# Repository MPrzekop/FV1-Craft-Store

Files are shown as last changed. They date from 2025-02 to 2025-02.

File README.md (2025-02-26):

# Craft Store
#### FV-1 based multi-effect development platform that (almost) fits inside 1590b enclosure
Craft Store is a pedalboard friendly implementation of FV-1 with onboard USB programmer.
 <p align="center">
thumbnail
 </p>
 
---

How it's different
---
On top of the default signal path:
- there's physical feedback loop going from right channel output to the left channel input 
- FV-1's left channel input can be blended into the pedal's output 

Controls:
---
- 0-2 FV-1 potentiometer inputs
- Volume
- mix - full dry to full wet
- clock - 4049 based variable sampling clock 42kHz down to super glitchy 2kHz
- feed - adds FV-1's left channel output to the output signal
- toggle - switches between built-in FV-1 programs and EEPROM
- 8 position program selector

Contents:
---
- [KiCad 8.0 project ](https://github.com/MPrzekop/FV1-Craft-Store/tree/main/Hardware/KiCad)
  - 2 effect boards and optional footswitch doughterboard
<p align="center">
pcb 3d render
schematic layout
pcb layout
 </p>
 
 - [3D printing files ](https://github.com/MPrzekop/FV1-Craft-Store/tree/main/Hardware/3DPrinting)
    - Case and lid, similar to 1590b just 2mm taller 
    - Knobs for 9mm potentiometers V6 is different from V5 that it has an inset to accommodate for 8 position switch thread collar. V5 variants to use depending on filament and printer.
 - [Spincad made example programs ](https://github.com/MPrzekop/FV1-Craft-Store/tree/main/Software)

Build Guide:
---
[BOM](https://github.com/MPrzekop/FV1-Craft-Store/blob/main/Hardware/KiCad/fv1.csv).

Most of the components are SMD so it may require some experience. I've tried to preserve both component ids and values on the PCB itself for ease of build and debugging.

Couple of tips:
- with normal 2.54 sockets and pins the boards may pivot on DC jack, I've soldered sockets when the board was lying on a flat surface to get the most clearance from the pins.
- Clock potentiometer is marked as 100K, this may be excessive as below 20kHz there's an audible hiss. I've tested with 20K and it was more controllable, but still glitchy (theoretically going down to 8kHz). If what you need is longer delays without much audio degradation I'd recommend putting 5K potentiometer there.
- The board stack is slightly too tall for a normal 1590b housing, to make the housing compatible you'll need to file down the lip on the lid, or add around 2mm spacing between the housing and the lid. 

Programming Guide:
---

On the board there's a **[ch341a](https://www.wch-ic.com/products/CH341.html)** programmer and **[24lc32](https://ww1.microchip.com/downloads/en/DeviceDoc/21072G.pdf)** EEPROM so any approaches for programming those are valid.
- you'll need drivers from the [ch341a vendor's page](https://www.wch-ic.com/products/CH341.html)
- follow [this tutorial](https://wiki.pedalpcb.com/wiki/Using_the_FV1Dev_on_Microsoft_Windows) for how to program the EEPROM

Creating programs:
---

[Best place to start](https://electric-canary.com/fv1start.html)

- The easiest way, by a mile, is to use [SpinCAD designer](https://github.com/HolyCityAudio/SpinCAD-Designer) 

<p align="center">
spincad
</p>

- [SpinASM](https://spinsemi.com/products.html), FV-1 flavoured assembly 

<p align="center">
pcb 3d render
</p>

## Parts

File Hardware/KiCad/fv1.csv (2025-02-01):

Reference | Value | Datasheet | Footprint | Qty | DNP
3V3 | TestPoint | ~ | Connector_PinHeader_1.00mm:PinHeader_1x01_P1.00mm_Vertical | 1
C1,C2 | 47u | ~ | Capacitor_SMD:CP_Elec_5x5.4 | 2
C3,C4 | 20p | ~ | Capacitor_SMD:C_0603_1608Metric_Pad1.08x0.95mm_HandSolder | 2
C5,C6,C8,C9,C11,C22,C29,C31 | 100n | ~ | Capacitor_SMD:C_0603_1608Metric_Pad1.08x0.95mm_HandSolder | 8
C7 | 100u | ~ | Capacitor_SMD:CP_Elec_6.3x5.4 | 1
C10 | 330n | ~ | Capacitor_SMD:C_0603_1608Metric_Pad1.08x0.95mm_HandSolder | 1
C12,C14,C15,C16,C17,C18,C21,C24 | 1u | ~ | Capacitor_SMD:C_0603_1608Metric_Pad1.08x0.95mm_HandSolder | 8
C13,C23,C25 | 2n2 | ~ | Capacitor_SMD:C_0603_1608Metric_Pad1.08x0.95mm_HandSolder | 3
C19 | 220p | ~ | Capacitor_SMD:C_0603_1608Metric_Pad1.08x0.95mm_HandSolder | 1
C20,C28 | 470p | ~ | Capacitor_SMD:C_0603_1608Metric_Pad1.08x0.95mm_HandSolder | 2
C30 | 4.7u | ~ | Capacitor_SMD:C_0603_1608Metric_Pad1.08x0.95mm_HandSolder | 1
D1,D12 | 1N5817 | http://www.vishay.com/docs/88525/1n5817.pdf | Diode_THT:D_DO-41_SOD81_P10.16mm_Horizontal | 2
D2 | LED | ~ | LED_THT:LED_D5.0mm | 1
D3,D4,D5,D6,D7,D8,D9,D10,D11 | 1N914 | https://datasheet.octopart.com/1N914ATR-ON-Semiconductor-datasheet-42765246.pdf | Diode_SMD:D_SOD-323_HandSoldering | 9
J1 | USB_B_Micro | ~ | FV1Footrpints:USB_Micro-AB_Molex_47590-0001 | 1
J3,J9,J10 | Conn_01x02_Socket | ~ | Connector_PinSocket_2.54mm:PinSocket_1x02_P2.54mm_Vertical | 3
J4,J5,J6,J7 | Conn_01x13 | ~ | -- mixed values -- | 4
J8 | Barrel_Jack_MountingPin | ~ | Connector_BarrelJack:BarrelJack_Horizontal | 1
R1,R2,R5,R6,RV6 | 10K | ~ | -- mixed values -- | 5
R3 | 4K7 | ~ | PCM_4ms_Resistor:R_0603 | 1
R4 | 2k2 | ~ | PCM_4ms_Resistor:R_0603 | 1
R7,R8,R9,R24,RV1,RV2,RV3,RV4 | 100K | ~ | -- mixed values -- | 8
R10,R13,R16,R26 | 1K | ~ | PCM_4ms_Resistor:R_0603 | 4
R11,R12 | 1M | ~ | PCM_4ms_Resistor:R_0603 | 2
R14 | 20K | ~ | PCM_4ms_Resistor:R_0603 | 1
R15,R23 | 100 | ~ | PCM_4ms_Resistor:R_0603 | 2
R17,R18,R19,R20,R21,R22,R29,R30,R31 | 15K | ~ | PCM_4ms_Resistor:R_0603 | 9
RV5 | B10K | ~ | PCM_4ms_Potentiometer:Pot_9mm_Knurl_NoDet | 1
SW1,SW3,SW4,SW5 | SW_SPDT | ~ | -- mixed values -- | 4
SW2 | SW_Rotary_1x8_MP | ~ | FV1Footrpints:SR16 | 1
U1 | SPN1001 | http://www.spinsemi.com/Products/datasheets/spn1001/FV-1.pdf | Package_SO:SOIC-28W_7.5x17.9mm_P1.27mm | 1
U2 | L78L33_TO92 | http://www.st.com/content/ccc/resource/technical/document/datasheet/15/55/e5/aa/23/5b/43/fd/CD00000446.pdf/files/CD00000446.pdf/jcr:content/translations/en.CD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 | Package_TO_SOT_THT:TO-92_Inline | 1
U3 | 24LC32 | http://ww1.microchip.com/downloads/en/DeviceDoc/21072G.pdf | Package_DIP:DIP-8_W7.62mm_Socket | 1
U4 | CH341A |  | Package_SO:SOIC-28W_7.5x18.7mm_P1.27mm | 1
U6 | TL074 | http://www.ti.com/lit/ds/symlink/tl071.pdf | Package_DIP:DIP-14_W7.62mm_Socket | 1
U8 | ATtiny85-20P | http://ww1.microchip.com/downloads/en/DeviceDoc/atmel-2586-avr-8-bit-microcontroller-attiny25-attiny45-attiny85_datasheet.pdf | Package_DIP:DIP-8_W7.62mm | 1
Y1 | 12Mhz | ~ | Crystal:Crystal_HC49-4H_Vertical | 1

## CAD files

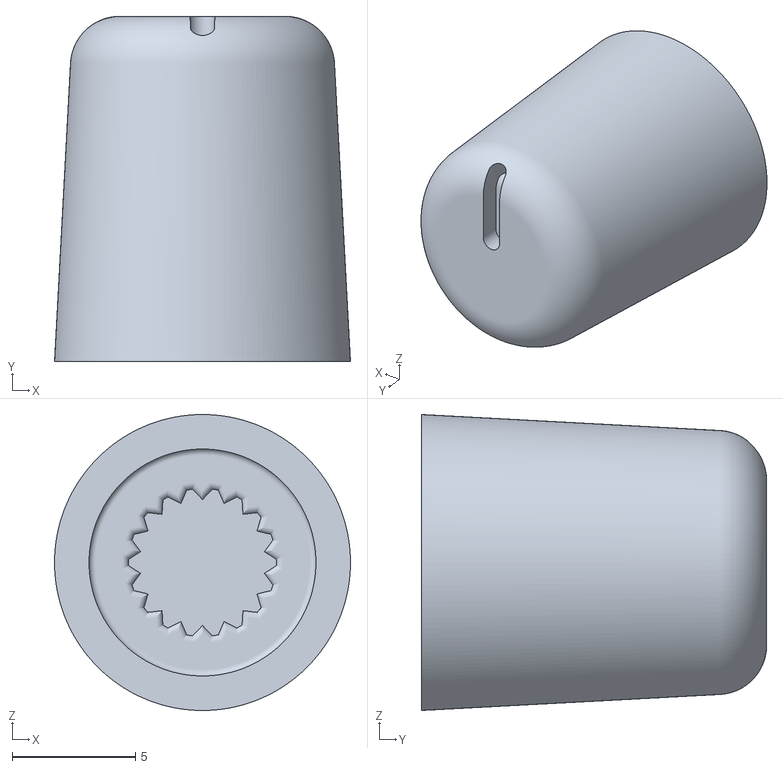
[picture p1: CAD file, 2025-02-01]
Hardware/3DPrinting/Knob v5 0 tolerance.stl
12.0 x 14.0 x 12.0

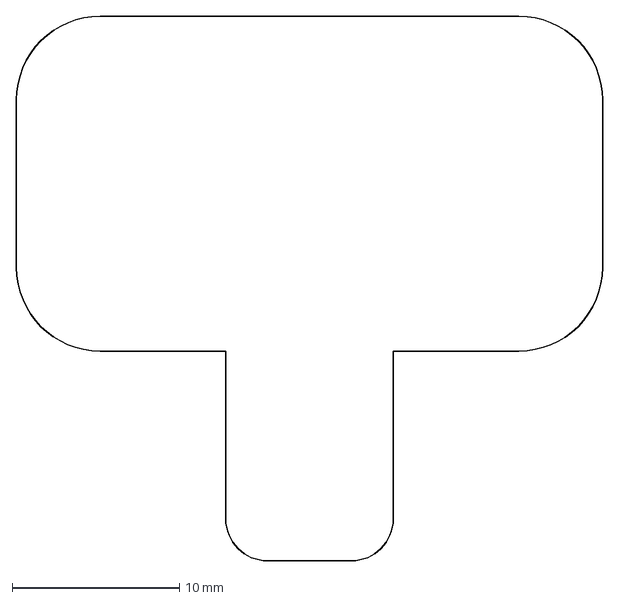
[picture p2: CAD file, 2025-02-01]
Hardware/Drawings/FootSwitchEdgeCuts.dxf
35.0 x 32.5 mm

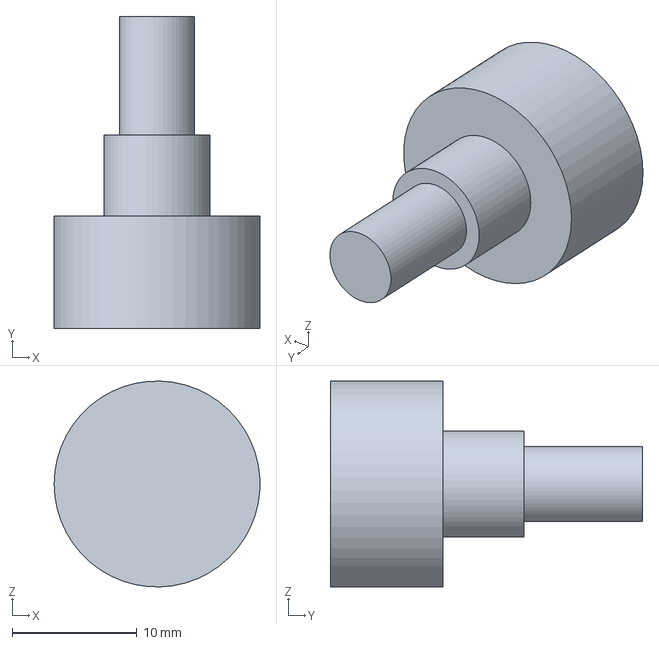
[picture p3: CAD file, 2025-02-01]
Hardware/KiCad/8Pos switch placeholder v1.step
16.5 x 25.0 x 16.5 mm

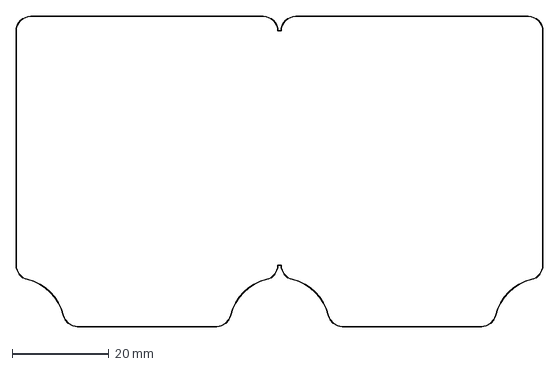
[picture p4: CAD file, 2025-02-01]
Hardware/Drawings/edgecutsCombined.dxf
108.7 x 64.0 mm

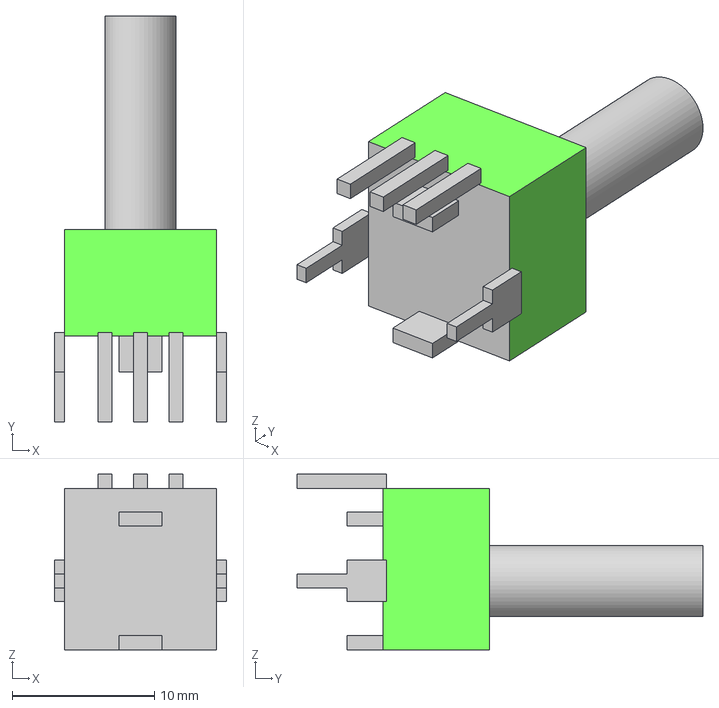
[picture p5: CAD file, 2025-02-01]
Hardware/KiCad/RL09L placeholder v1.step
12.1 x 28.5 x 12.3 mm

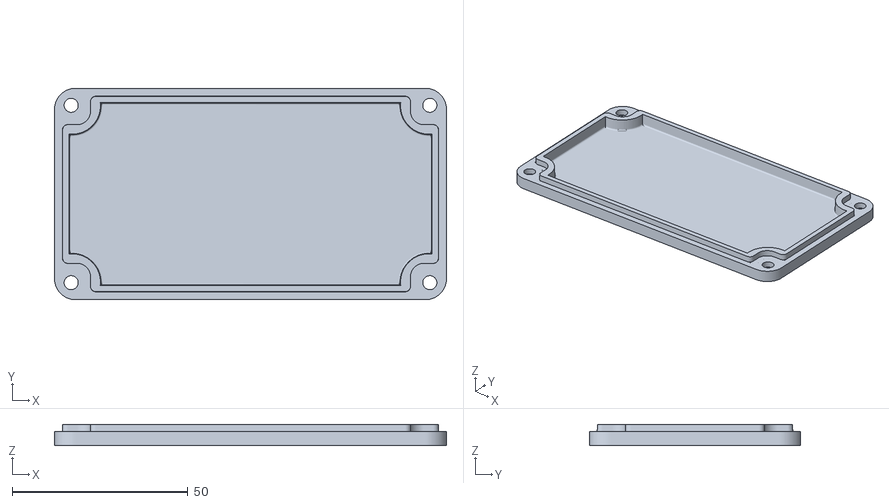
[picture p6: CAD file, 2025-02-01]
Hardware/3DPrinting/1590B-BS LID.stl
111.6 x 60.2 x 6.00

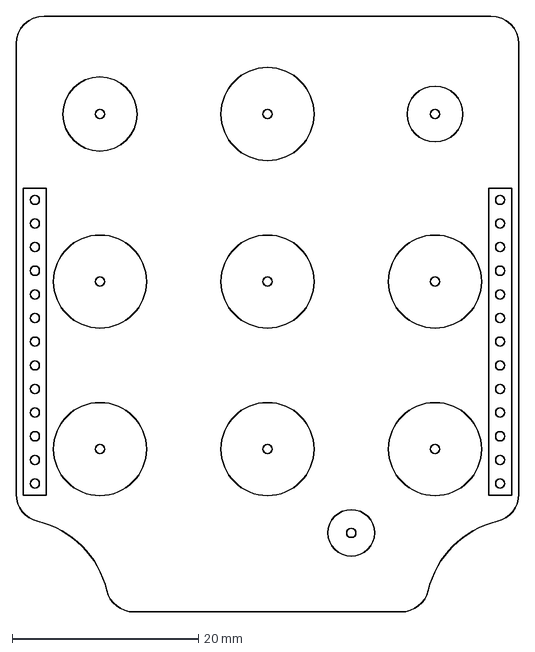
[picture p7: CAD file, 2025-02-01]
Hardware/Drawings/TopDrawingLED.dxf
54.0 x 64.0 mm

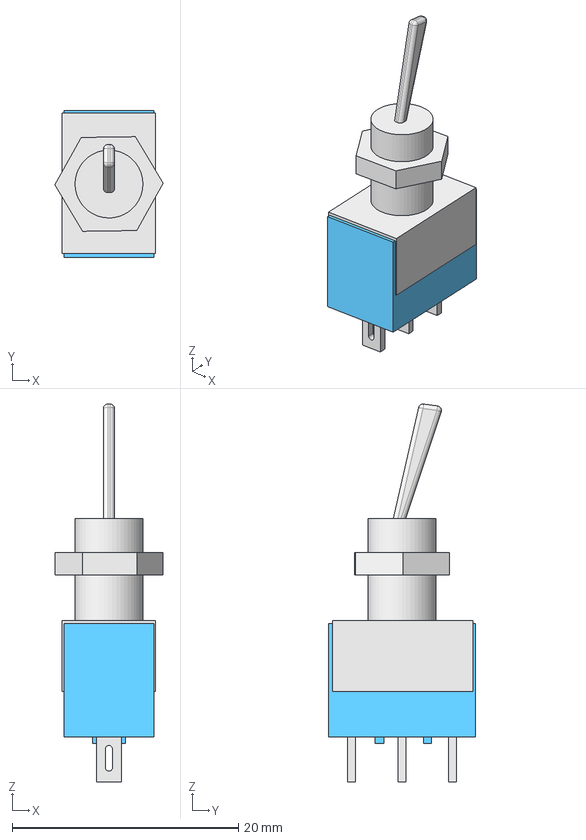
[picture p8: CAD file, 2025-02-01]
Hardware/KiCad/Toggle_SW_Blue_R0.step
9.58 x 13.0 x 33.4 mm
Housing
Chrome

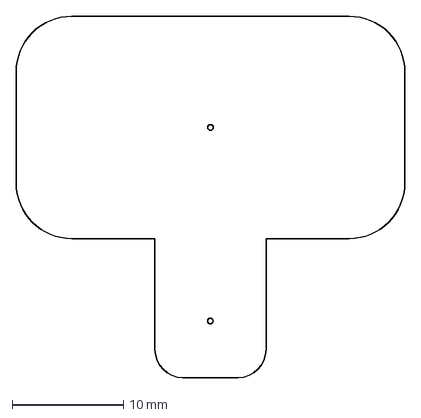
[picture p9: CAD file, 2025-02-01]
Hardware/Drawings/FootswitchBoard drawings.dxf
35.0 x 32.5 mm

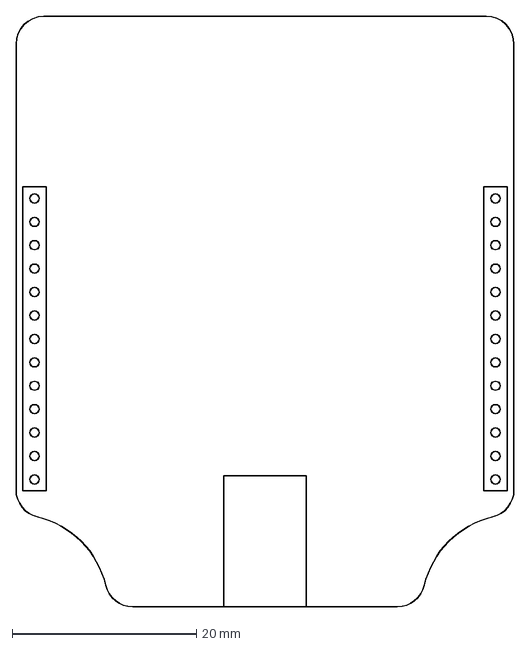
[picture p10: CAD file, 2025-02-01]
Hardware/Drawings/BottomDrawing with dc jack placement.dxf
54.0 x 64.0 mm

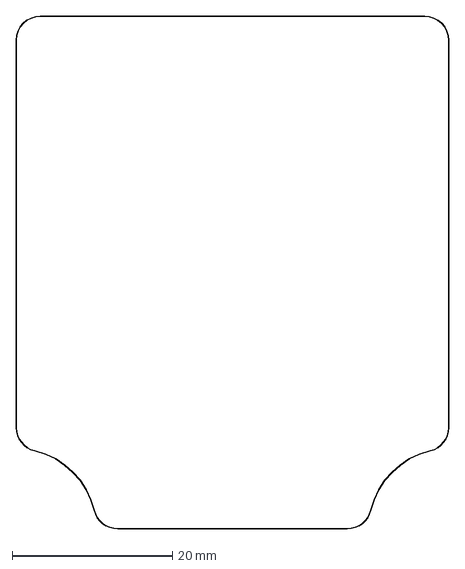
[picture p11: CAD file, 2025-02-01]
Hardware/Drawings/edgecuts.dxf
54.0 x 64.0 mm

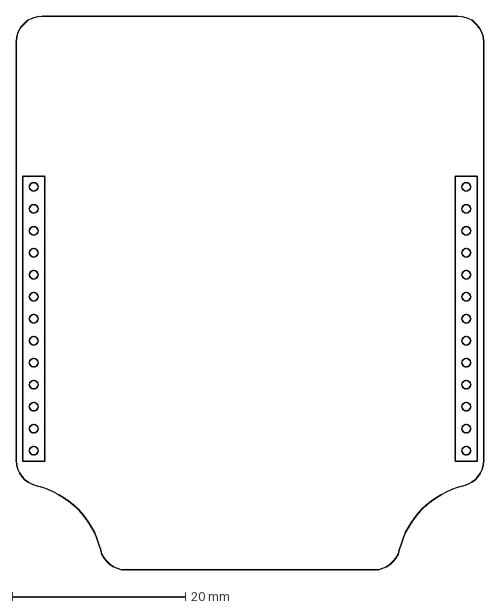
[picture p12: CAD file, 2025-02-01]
Hardware/Drawings/bottom drawing.dxf
54.0 x 64.0 mm

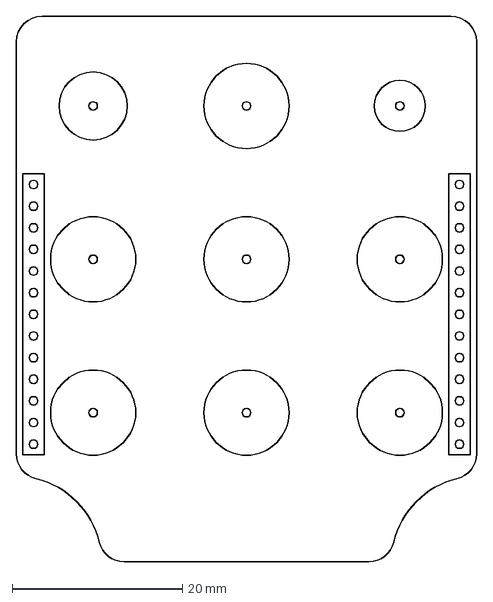
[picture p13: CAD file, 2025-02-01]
Hardware/Drawings/Drawing.dxf
54.0 x 64.0 mm

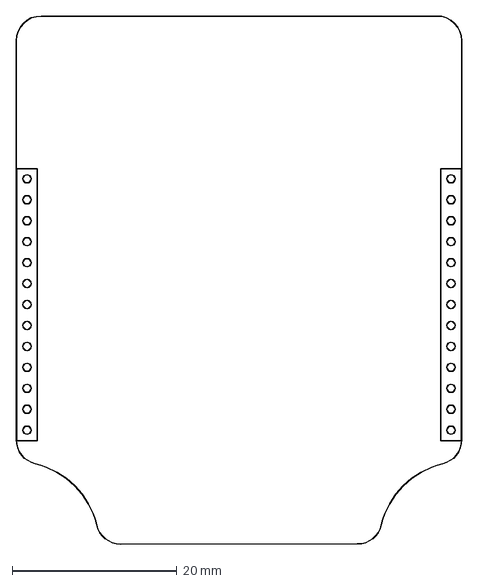
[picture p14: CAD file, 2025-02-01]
Hardware/Drawings/BottomPlate outline.dxf
54.0 x 64.0 mm

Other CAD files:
Hardware/3DPrinting/Knob v5.stl
Hardware/Drawings/LedTopDrawing.dxf
Hardware/KiCad/8Pos switch placeholder v1.obj

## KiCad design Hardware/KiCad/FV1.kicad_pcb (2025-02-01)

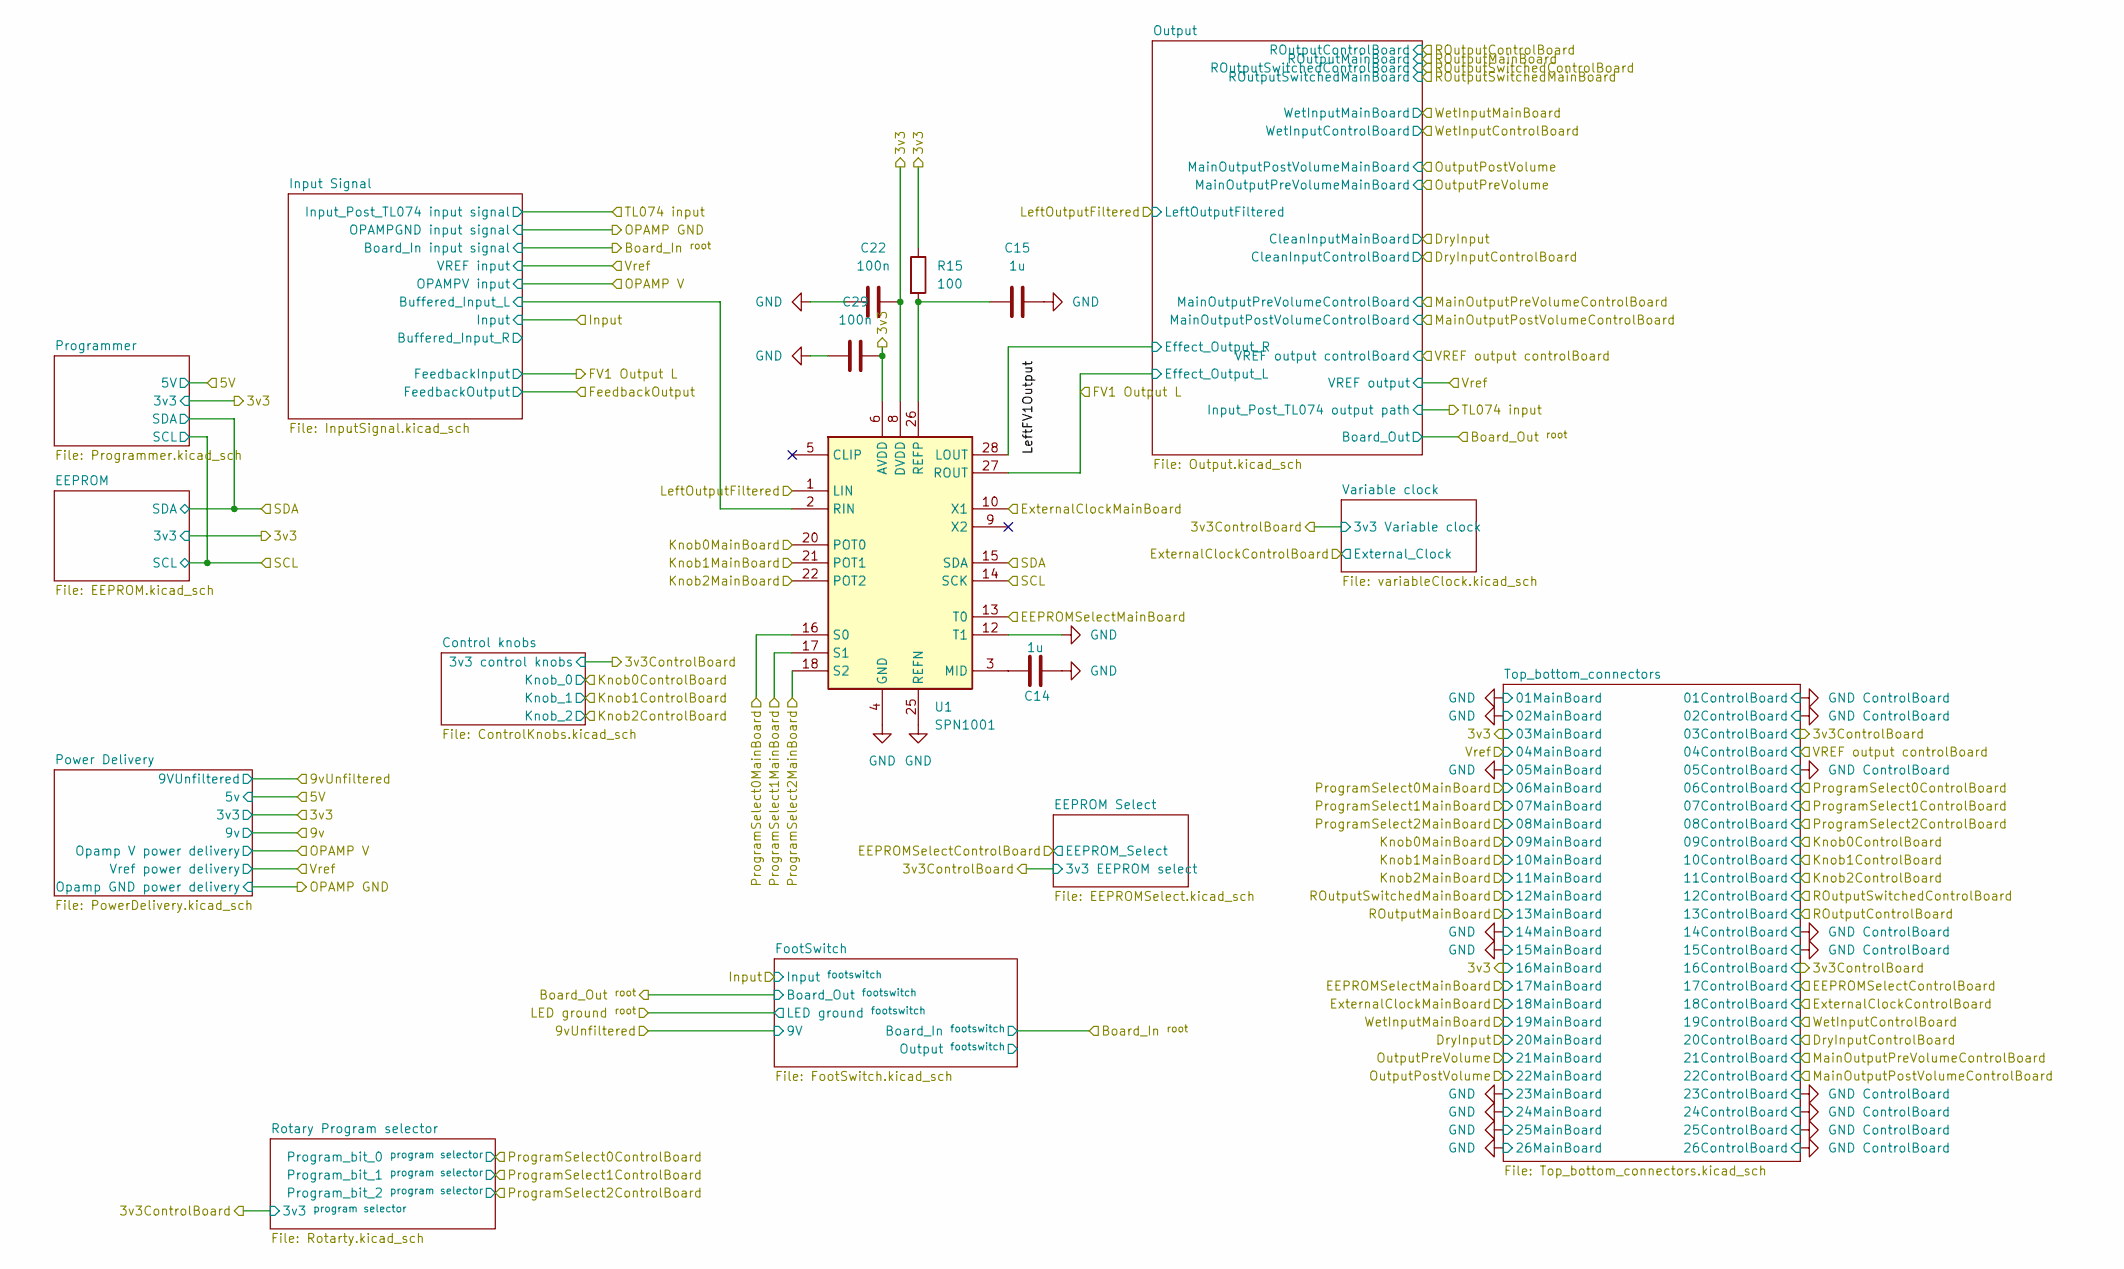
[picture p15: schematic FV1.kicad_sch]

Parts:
C14, C15: 1u; C_0603_1608Metric_Pad1.08x0.95mm_HandSolder
C22, C29: 100n; C_0603_1608Metric_Pad1.08x0.95mm_HandSolder
R15: 100; R_0603
U1: SPN1001; SOIC-28W_7.5x17.9mm_P1.27mm

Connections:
/3v3: C22.2, C29.2, R15.1, U1.6 (AVDD), U1.8 (DVDD), U1.23 (DVDD); also elsewhere on the board
/EEPROMSelectMainBoard: U1.13 (T0); also elsewhere on the board
/ExternalClockMainBoard: U1.10 (X1); also elsewhere on the board
/FV1 Output L: U1.27 (ROUT); also elsewhere on the board
/Input Signal/Buffered_Input_L: U1.2 (RIN); also elsewhere on the board
/Knob0MainBoard: U1.20 (POT0); also elsewhere on the board
/Knob1MainBoard: U1.21 (POT1); also elsewhere on the board
/Knob2MainBoard: U1.22 (POT2); also elsewhere on the board
/LeftOutputFiltered: U1.1 (LIN); also elsewhere on the board
/Output/Effect_Output_R: U1.28 (LOUT); also elsewhere on the board
/ProgramSelect0MainBoard: U1.16 (S0); also elsewhere on the board
/ProgramSelect1MainBoard: U1.17 (S1); also elsewhere on the board
/ProgramSelect2MainBoard: U1.18 (S2); also elsewhere on the board
/SCL: U1.14 (SCK); also elsewhere on the board
/SDA: U1.15 (SDA); also elsewhere on the board
GND: C14.1, C15.2, C22.1, C29.1, U1.4 (GND), U1.7 (GND), U1.11 (GND), U1.12 (T1), U1.19 (GND), U1.24 (GND), U1.25 (REFN); also elsewhere on the board
unnamed: C14.2, U1.3 (MID)
unnamed: C15.1, R15.2, U1.26 (REFP)

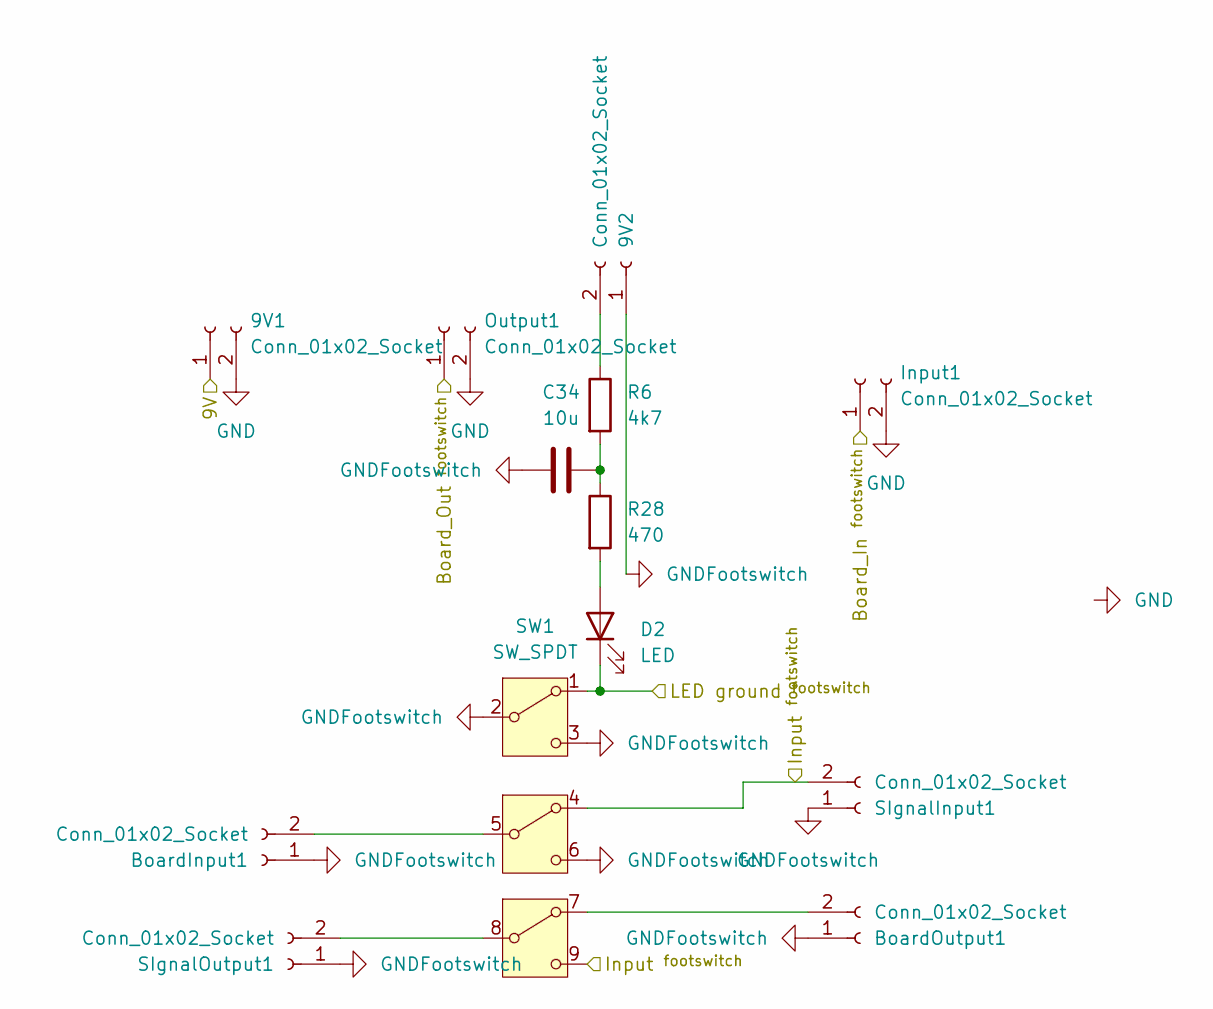
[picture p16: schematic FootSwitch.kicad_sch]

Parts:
9V1, 9V2: Conn_01x02_Socket; PinSocket_1x02_P2.54mm_Vertical
BoardInput1: Conn_01x02_Socket; PinSocket_1x02_P2.54mm_Vertical
BoardOutput1: Conn_01x02_Socket; PinSocket_1x02_P2.54mm_Vertical
C34: 10u; C_0603_1608Metric_Pad1.08x0.95mm_HandSolder
D2: LED; LED_D5.0mm
Input1: Conn_01x02_Socket; PinSocket_1x02_P2.54mm_Vertical
Output1: Conn_01x02_Socket; PinSocket_1x02_P2.54mm_Vertical
R6: 4k7; R_0603
R28: 470; R_0603
SIgnalInput1: Conn_01x02_Socket; PinSocket_1x02_P2.54mm_Vertical
SIgnalOutput1: Conn_01x02_Socket; PinSocket_1x02_P2.54mm_Vertical
SW1: SW_SPDT; 3PDT

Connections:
/9vUnfiltered: 9V1.1; also elsewhere on the board
/Board_Out ^{root}: Output1.1; also elsewhere on the board
/Input: SIgnalInput1.2, SW1.4 (A2), SW1.9 (C3)
/Input Signal/PrefilteredInput: Input1.1; also elsewhere on the board
/LED ground ^{root}: D2.1 (K), SW1.1 (A)
GND: 9V1.2, Input1.2, Output1.2; also elsewhere on the board
GNDFootswitch: 9V2.1, BoardInput1.1, BoardOutput1.1, C34.1, SIgnalInput1.1, SIgnalOutput1.1, SW1.2 (B), SW1.3 (C), SW1.6 (C2)
unnamed: 9V2.2, R6.1
unnamed: BoardInput1.2, SW1.5 (B2)
unnamed: BoardOutput1.2, SW1.7 (A3)
unnamed: C34.2, R6.2, R28.1
unnamed: D2.2 (A), R28.2
unnamed: SIgnalOutput1.2, SW1.8 (B3)

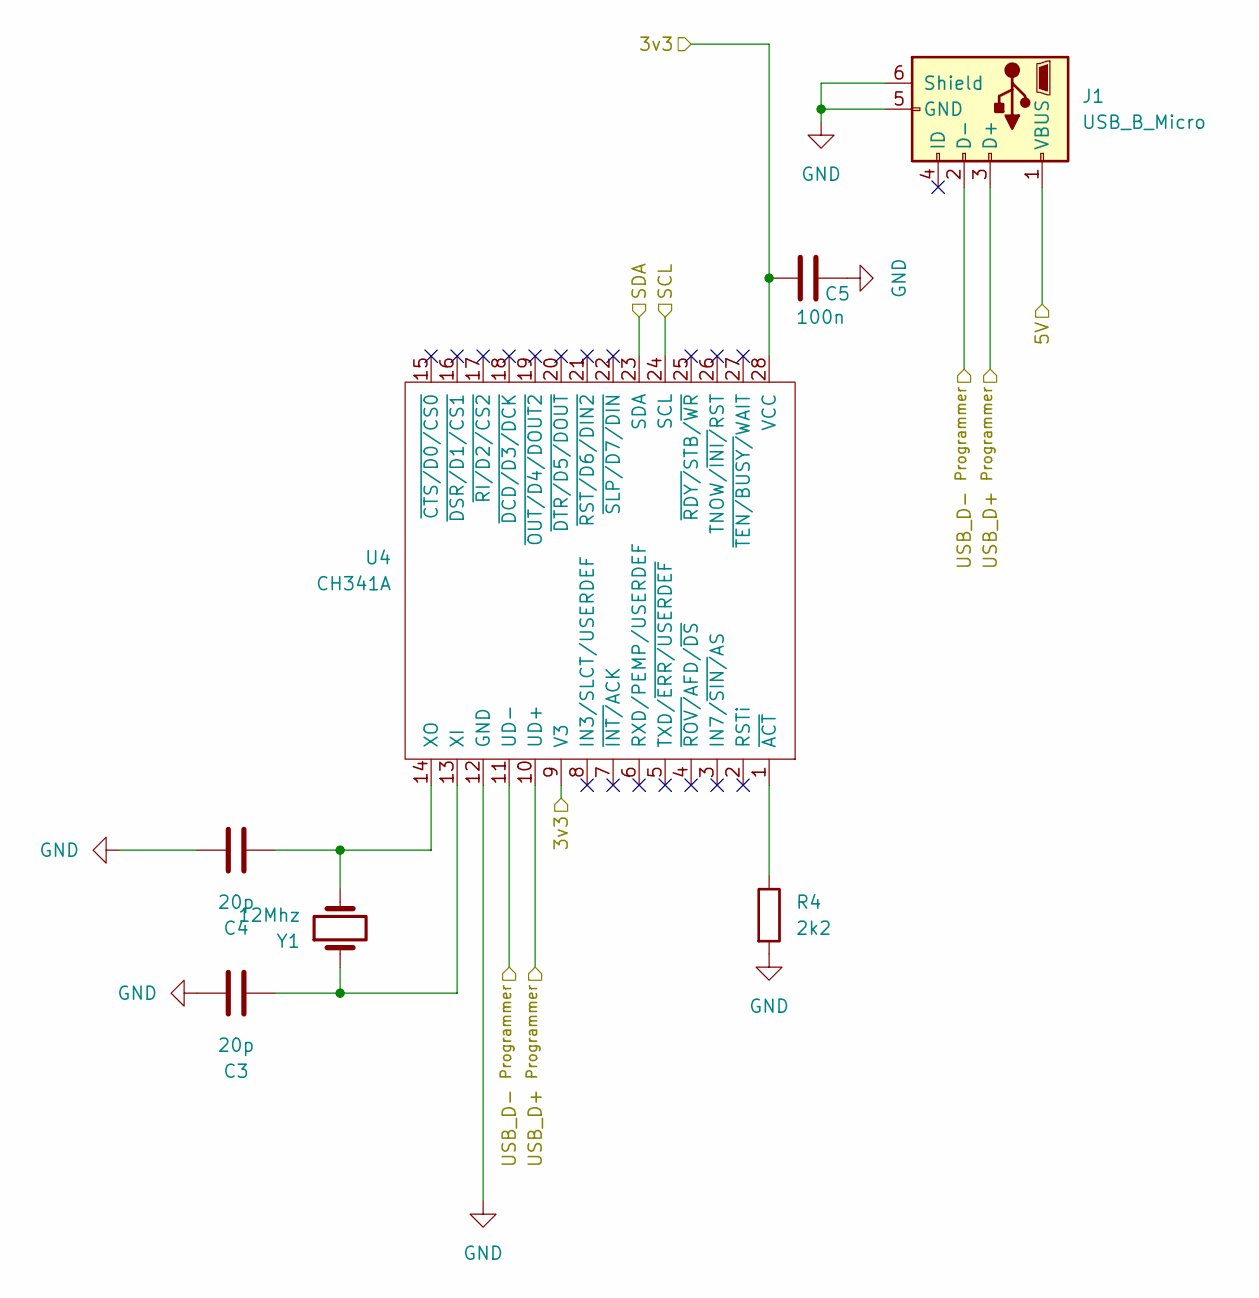
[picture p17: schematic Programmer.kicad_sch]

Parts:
C3, C4: 20p; C_0603_1608Metric_Pad1.08x0.95mm_HandSolder
C5: 100n; C_0603_1608Metric_Pad1.08x0.95mm_HandSolder
J1: USB_B_Micro; USB_Micro-AB_Molex_47590-0001
R4: 2k2; R_0603
U4: CH341A; SOIC-28W_7.5x18.7mm_P1.27mm
Y1: 12Mhz; Crystal_HC49-4H_Vertical

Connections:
/3v3: C5.1, U4.9 (V3), U4.28 (VCC); also elsewhere on the board
/5V: J1.1 (VBUS); also elsewhere on the board
/Programmer/USB_D+ ^{Programmer}: J1.3 (D+), U4.10 (UD+)
/Programmer/USB_D- ^{Programmer}: J1.2 (D-), U4.11 (UD-)
/SCL: U4.24 (SCL); also elsewhere on the board
/SDA: U4.23 (SDA); also elsewhere on the board
GND: C3.2, C4.2, C5.2, J1.5 (GND), J1.6 (Shield), R4.2, U4.12 (GND); also elsewhere on the board
unnamed: C3.1, U4.13 (XI), Y1.1
unnamed: C4.1, U4.14 (XO), Y1.2
unnamed: R4.1, U4.1 (~ACT)

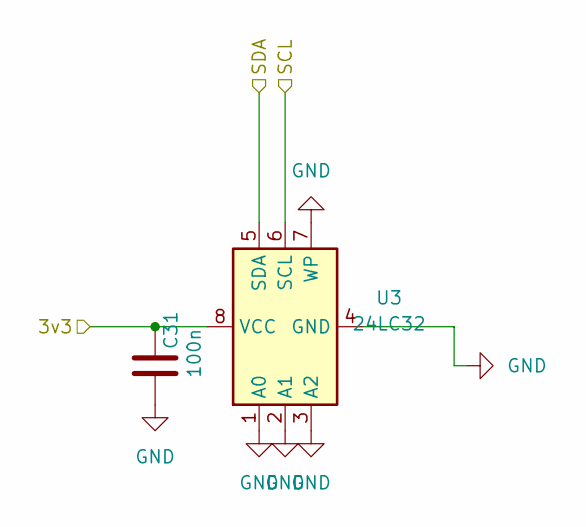
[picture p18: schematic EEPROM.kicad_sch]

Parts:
C31: 100n; C_0603_1608Metric_Pad1.08x0.95mm_HandSolder
U3: 24LC32; DIP-8_W7.62mm_Socket

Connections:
/3v3: C31.2, U3.8 (VCC); also elsewhere on the board
/SCL: U3.6 (SCL); also elsewhere on the board
/SDA: U3.5 (SDA); also elsewhere on the board
GND: C31.1, U3.1 (A0), U3.2 (A1), U3.3 (A2), U3.4 (GND), U3.7 (WP); also elsewhere on the board

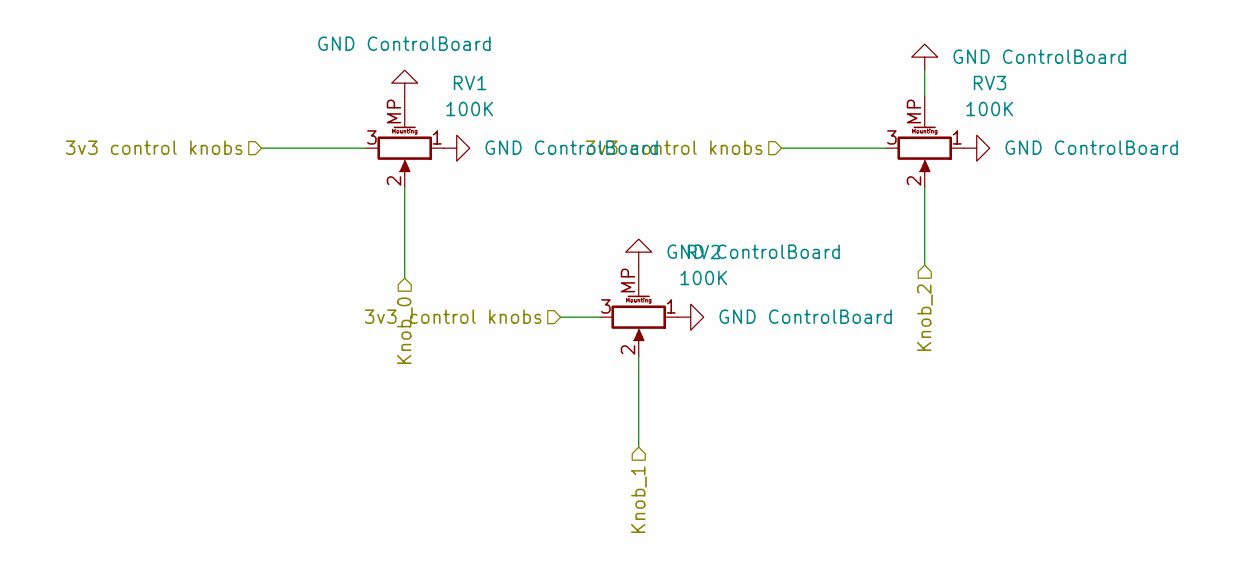
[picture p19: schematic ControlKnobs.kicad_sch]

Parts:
RV1, RV2, RV3: 100K; Pot_9mm_Knurl_NoDet

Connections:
/EEPROM Select/3v3: RV1.3, RV2.3, RV3.3; also elsewhere on the board
/Knob0ControlBoard: RV1.2; also elsewhere on the board
/Knob1ControlBoard: RV2.2; also elsewhere on the board
/Knob2ControlBoard: RV3.2; also elsewhere on the board
GND ControlBoard: RV1.1, RV1.MP (MountPin), RV2.1, RV2.MP (MountPin), RV3.1, RV3.MP (MountPin); also elsewhere on the board

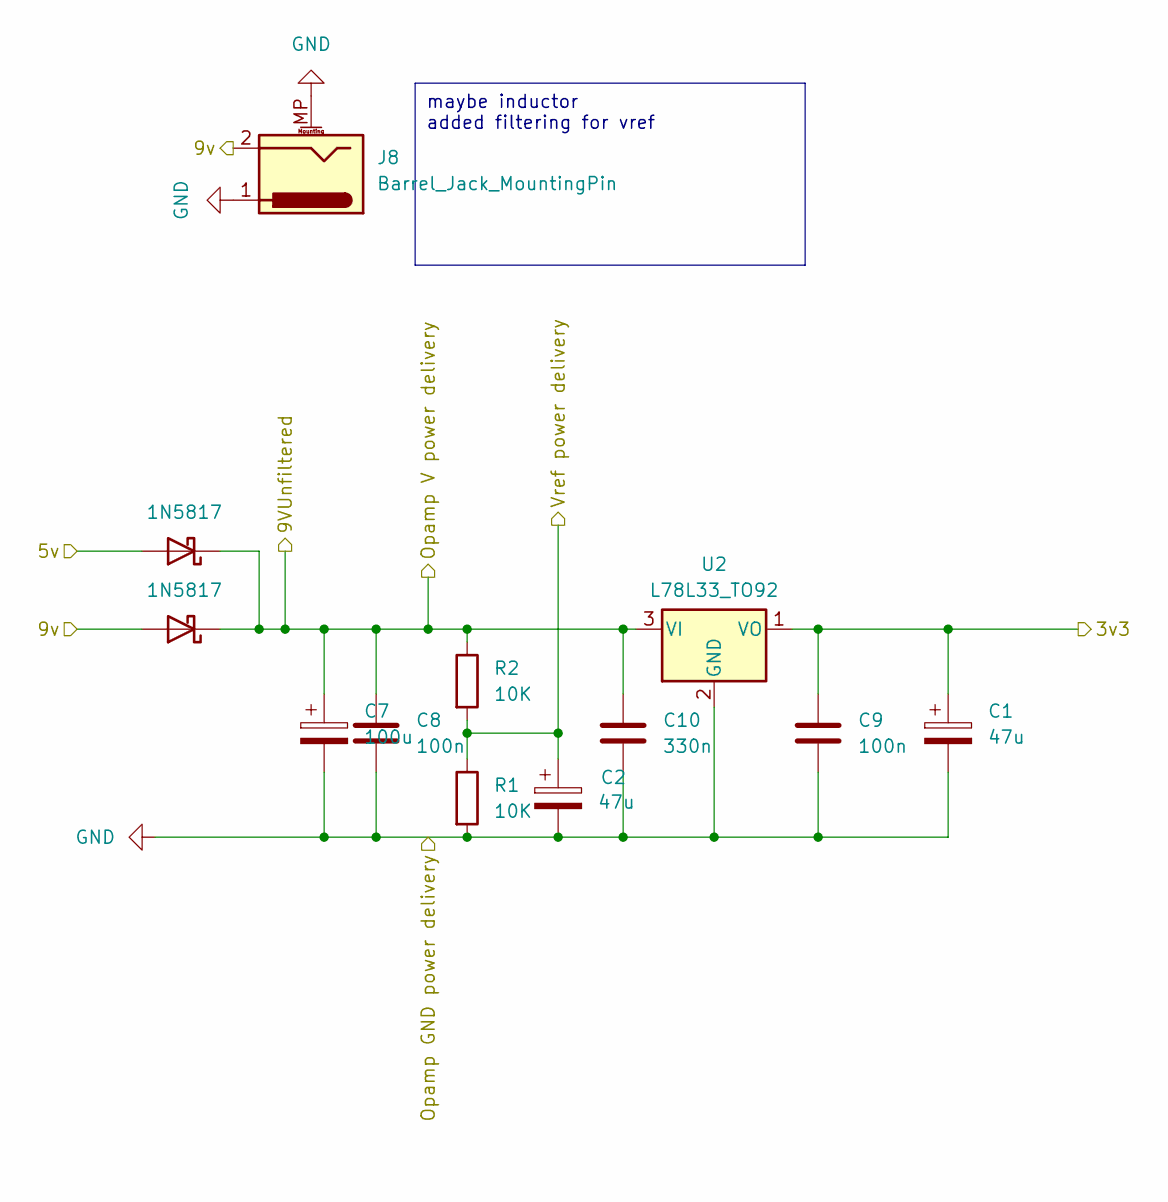
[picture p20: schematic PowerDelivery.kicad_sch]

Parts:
C1, C2: 47u; CP_Elec_5x5.4
C7: 100u; CP_Elec_6.3x5.4
C8, C9: 100n; C_0603_1608Metric_Pad1.08x0.95mm_HandSolder
C10: 330n; C_0603_1608Metric_Pad1.08x0.95mm_HandSolder
D1, D12: 1N5817; D_DO-41_SOD81_P10.16mm_Horizontal
J8: Barrel_Jack_MountingPin; BarrelJack_Horizontal
R1, R2: 10K; R_0603
U2: L78L33_TO92; TO-92_Inline

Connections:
/3v3: C1.1, C9.1, U2.1 (VO); also elsewhere on the board
/5V: D12.2 (A); also elsewhere on the board
/9v: D1.2 (A), J8.2
/9vUnfiltered: C7.1, C8.1, C10.1, D1.1 (K), D12.1 (K), R2.1, U2.3 (VI); also elsewhere on the board
/Vref: C2.1, R1.1, R2.2; also elsewhere on the board
GND: C1.2, C2.2, C7.2, C8.2, C9.2, C10.2, J8.1, J8.MP (MountPin), R1.2, U2.2 (GND); also elsewhere on the board

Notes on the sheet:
maybe inductor added filtering for vref

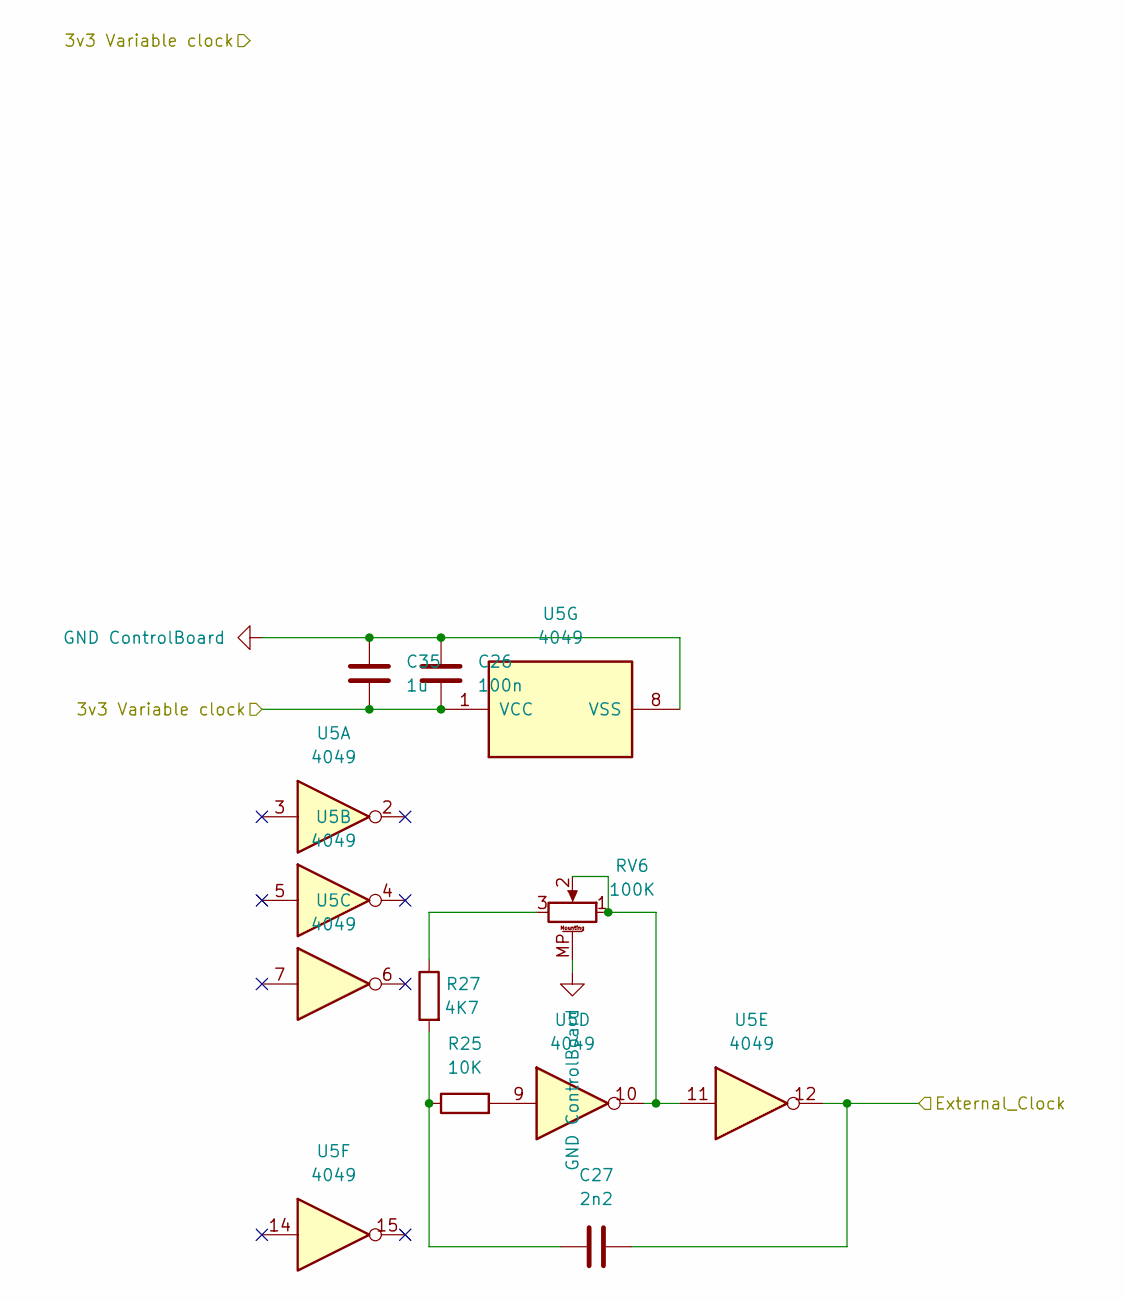
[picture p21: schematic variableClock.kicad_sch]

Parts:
C26: 100n; C_0603_1608Metric_Pad1.08x0.95mm_HandSolder
C27: 2n2; C_0603_1608Metric_Pad1.08x0.95mm_HandSolder
C35: 1u; C_0603_1608Metric_Pad1.08x0.95mm_HandSolder
R25: 10K; R_0603
R27: 4K7; R_0603
RV6: 100K; Pot_9mm_Knurl_NoDet
U5: 4049; CERDIP-16_W7.62mm_SideBrazed

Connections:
/EEPROM Select/3v3: C26.2, C35.2, U5.1 (VCC); also elsewhere on the board
/ExternalClockControlBoard: C27.2, U5.12; also elsewhere on the board
GND ControlBoard: C26.1, C35.1, RV6.MP (MountPin), U5.8 (VSS); also elsewhere on the board
unnamed: C27.1, R25.1, R27.2
unnamed: R25.2, U5.9
unnamed: R27.1, RV6.3
unnamed: RV6.1, RV6.2, U5.10, U5.11

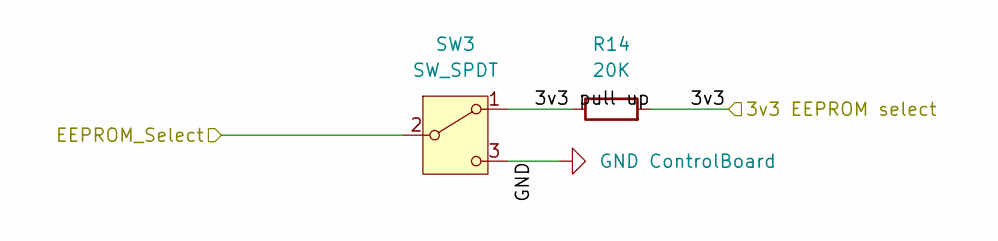
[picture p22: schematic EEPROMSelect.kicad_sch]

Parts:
R14: 20K; R_0603
SW3: SW_SPDT; SW_Toggle_Blue_wSlots

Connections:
/EEPROM Select/3v3: R14.2; also elsewhere on the board
/EEPROMSelectControlBoard: SW3.2 (B); also elsewhere on the board
GND ControlBoard: SW3.3 (C); also elsewhere on the board
unnamed: R14.1, SW3.1 (A)

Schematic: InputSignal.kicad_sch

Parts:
C6, C11, C36: 100n; C_0603_1608Metric_Pad1.08x0.95mm_HandSolder
C12: 1u; C_0603_1608Metric_Pad1.08x0.95mm_HandSolder
C13: 1n; C_0603_1608Metric_Pad1.08x0.95mm_HandSolder
R10, R13: 1K; R_0603
R11, R12: 1M; R_0603
U6: TL074; DIP-14_W7.62mm_Socket

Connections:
/9vUnfiltered: C6.1, U6.4 (V+); also elsewhere on the board
/Input Signal/Buffered_Input_L: C13.2, R13.2; also elsewhere on the board
/Input Signal/FilteredInput: R10.2, R12.1, U6.5 (+)
/Input Signal/PrefilteredInput: C11.1, R11.2; also elsewhere on the board
/TL074 input: C12.1, U6.6 (-), U6.7; also elsewhere on the board
/Vref: C36.2, R12.2; also elsewhere on the board
GND: C6.2, C13.1, C36.1, R11.1, U6.11 (V-); also elsewhere on the board
unnamed: C11.2, R10.1
unnamed: C12.2, R13.1

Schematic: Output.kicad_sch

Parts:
C16, C17, C18, C21, C24, C30: 1u; C_0603_1608Metric_Pad1.08x0.95mm_HandSolder
C19: 220p; C_0603_1608Metric_Pad1.08x0.95mm_HandSolder
C20, C28: 470p; C_0603_1608Metric_Pad1.08x0.95mm_HandSolder
C23, C25: 2n2; C_0603_1608Metric_Pad1.08x0.95mm_HandSolder
C32: 1n; C_0603_1608Metric_Pad1.08x0.95mm_HandSolder
C37, C38: 100n; C_0603_1608Metric_Pad1.08x0.95mm_HandSolder
R3, R16, R26: 1K; R_0603
R5, R17, R18, R19, R20, R21, R22, R30, R31: 15K; R_0603
R23: 100; R_0603
R24: 100K; R_0603
RV4: 100K; Pot_9mm_Knurl_NoDet
RV5, RV7: B10K; Pot_9mm_Knurl_NoDet
U6: TL074; DIP-14_W7.62mm_Socket

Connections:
/Board_Out ^{root}: C21.2, R24.2; also elsewhere on the board
/DryInputControlBoard: RV5.3; also elsewhere on the board
/FV1 Output L: C16.1, C30.1; also elsewhere on the board
/LeftOutputFiltered: C32.2, R3.2; also elsewhere on the board
/MainOutputPostVolumeControlBoard: C19.2, RV4.2, RV4.3; also elsewhere on the board
/MainOutputPreVolumeControlBoard: C19.1, RV4.1; also elsewhere on the board
/Output/DryInput: R18.2, R19.1; also elsewhere on the board
/Output/Effect_Output_R: C24.1; also elsewhere on the board
/Output/MixedBufferedOutput: R23.1, U6.1; also elsewhere on the board
/Output/MixedPrebufferedOutput: R19.2, R20.2, U6.2 (-); also elsewhere on the board
/ROutputControlBoard: RV7.3; also elsewhere on the board
/ROutputMainBoard: C25.2, R26.2; also elsewhere on the board
/ROutputSwitchedControlBoard: R5.2; also elsewhere on the board
/ROutputSwitchedMainBoard: C28.1, R30.1, R31.2, U6.13 (-); also elsewhere on the board
/TL074 input: R21.2; also elsewhere on the board
/VREF output controlBoard: C38.1, RV5.2, RV7.1; also elsewhere on the board
/Vref: C37.2, U6.3 (+), U6.10 (+), U6.12 (+); also elsewhere on the board
/WetInputControlBoard: RV5.1; also elsewhere on the board
/WetInputMainBoard: R17.2, R20.1; also elsewhere on the board
GND: C23.1, C25.1, C32.1, C37.1, R24.1; also elsewhere on the board
GND ControlBoard: C38.2, RV4.MP (MountPin), RV5.MP (MountPin), RV7.MP (MountPin); also elsewhere on the board
unnamed: C16.2, R16.1
unnamed: C17.1, C28.2, R31.1, U6.14
unnamed: C17.2, R17.1
unnamed: C18.1, C20.2, R22.2, U6.8
unnamed: C18.2, R18.1
unnamed: C21.1, R23.2
unnamed: C23.2, R16.2, R30.2
unnamed: C24.2, R26.1
unnamed: C30.2, R3.1
unnamed: R5.1, RV7.2
unnamed: C20.1, R21.1, R22.1, U6.9 (-)

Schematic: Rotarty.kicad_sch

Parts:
D3, D4, D5, D6, D7, D8, D9, D10, D11: 1N914; D_SOD-323_HandSoldering
R7, R8, R9: 100K; R_0603
SW2: SW_Rotary_1x8_MP; SR16

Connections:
/EEPROM Select/3v3: SW2.9; also elsewhere on the board
/ProgramSelect0ControlBoard: D3.1 (K), D5.1 (K), D9.1 (K), R7.1, SW2.2; also elsewhere on the board
/ProgramSelect1ControlBoard: D4.1 (K), D7.1 (K), D10.1 (K), R8.1, SW2.3; also elsewhere on the board
/ProgramSelect2ControlBoard: D6.1 (K), D8.1 (K), D11.1 (K), R9.1, SW2.5; also elsewhere on the board
GND ControlBoard: R7.2, R8.2, R9.2; also elsewhere on the board
unnamed: D3.2 (A), D4.2 (A), SW2.4
unnamed: D5.2 (A), D6.2 (A), SW2.6
unnamed: D7.2 (A), D8.2 (A), SW2.7
unnamed: D9.2 (A), D10.2 (A), D11.2 (A), SW2.8

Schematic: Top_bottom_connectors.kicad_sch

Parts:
J4, J5, J6: Conn_01x13; PinSocket_1x13_P2.54mm_Vertical
J7: Conn_01x13; PinHeader_1x13_P2.54mm_Vertical

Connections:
/3v3: J4.3, J5.3; also elsewhere on the board
/DryInputControlBoard: J7.7; also elsewhere on the board
/EEPROM Select/3v3: J6.3, J7.3; also elsewhere on the board
/EEPROMSelectControlBoard: J7.4; also elsewhere on the board
/EEPROMSelectMainBoard: J5.4; also elsewhere on the board
/ExternalClockControlBoard: J7.5; also elsewhere on the board
/ExternalClockMainBoard: J5.5; also elsewhere on the board
/Knob0ControlBoard: J6.9; also elsewhere on the board
/Knob0MainBoard: J4.9; also elsewhere on the board
/Knob1ControlBoard: J6.10; also elsewhere on the board
/Knob1MainBoard: J4.10; also elsewhere on the board
/Knob2ControlBoard: J6.11; also elsewhere on the board
/Knob2MainBoard: J4.11; also elsewhere on the board
/MainOutputPostVolumeControlBoard: J7.9; also elsewhere on the board
/MainOutputPreVolumeControlBoard: J7.8; also elsewhere on the board
/Output/DryInput: J5.7; also elsewhere on the board
/Output/MixedBufferedOutput: J5.9; also elsewhere on the board
/Output/MixedPrebufferedOutput: J5.8; also elsewhere on the board
/ProgramSelect0ControlBoard: J6.6; also elsewhere on the board
/ProgramSelect0MainBoard: J4.6; also elsewhere on the board
/ProgramSelect1ControlBoard: J6.7; also elsewhere on the board
/ProgramSelect1MainBoard: J4.7; also elsewhere on the board
/ProgramSelect2ControlBoard: J6.8; also elsewhere on the board
/ProgramSelect2MainBoard: J4.8; also elsewhere on the board
/ROutputControlBoard: J6.13; also elsewhere on the board
/ROutputMainBoard: J4.13; also elsewhere on the board
/ROutputSwitchedControlBoard: J6.12; also elsewhere on the board
/ROutputSwitchedMainBoard: J4.12; also elsewhere on the board
/VREF output controlBoard: J6.4; also elsewhere on the board
/Vref: J4.4; also elsewhere on the board
/WetInputControlBoard: J7.6; also elsewhere on the board
/WetInputMainBoard: J5.6; also elsewhere on the board
GND: J4.1, J4.2, J4.5, J5.1, J5.2, J5.10, J5.11, J5.12, J5.13; also elsewhere on the board
GND ControlBoard: J6.1, J6.2, J6.5, J7.1, J7.2, J7.10, J7.11, J7.12, J7.13; also elsewhere on the board

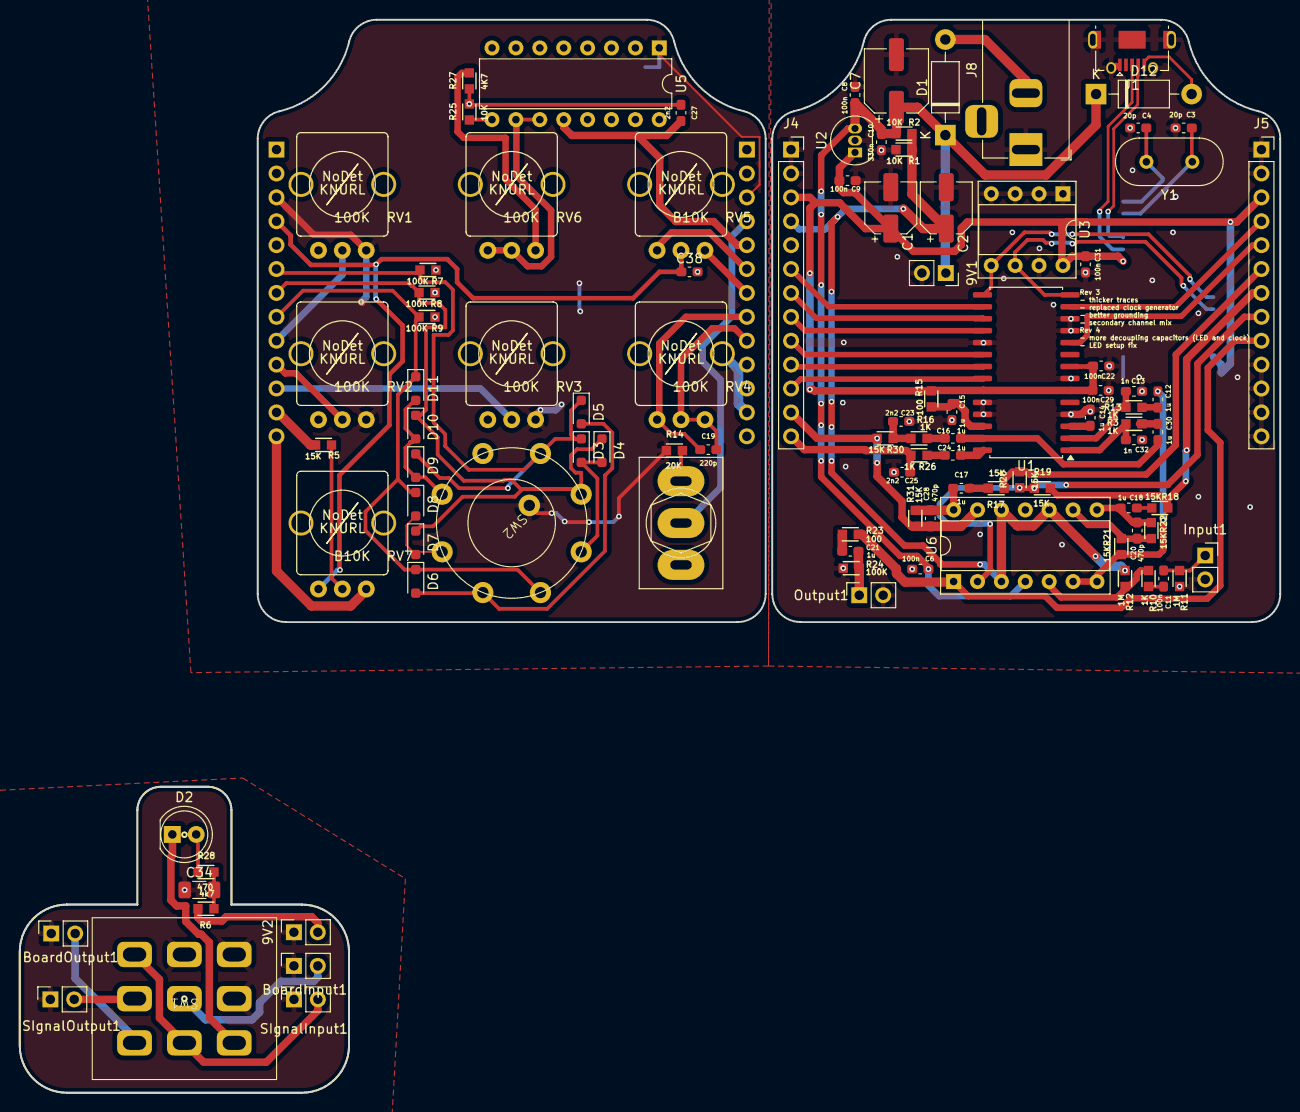
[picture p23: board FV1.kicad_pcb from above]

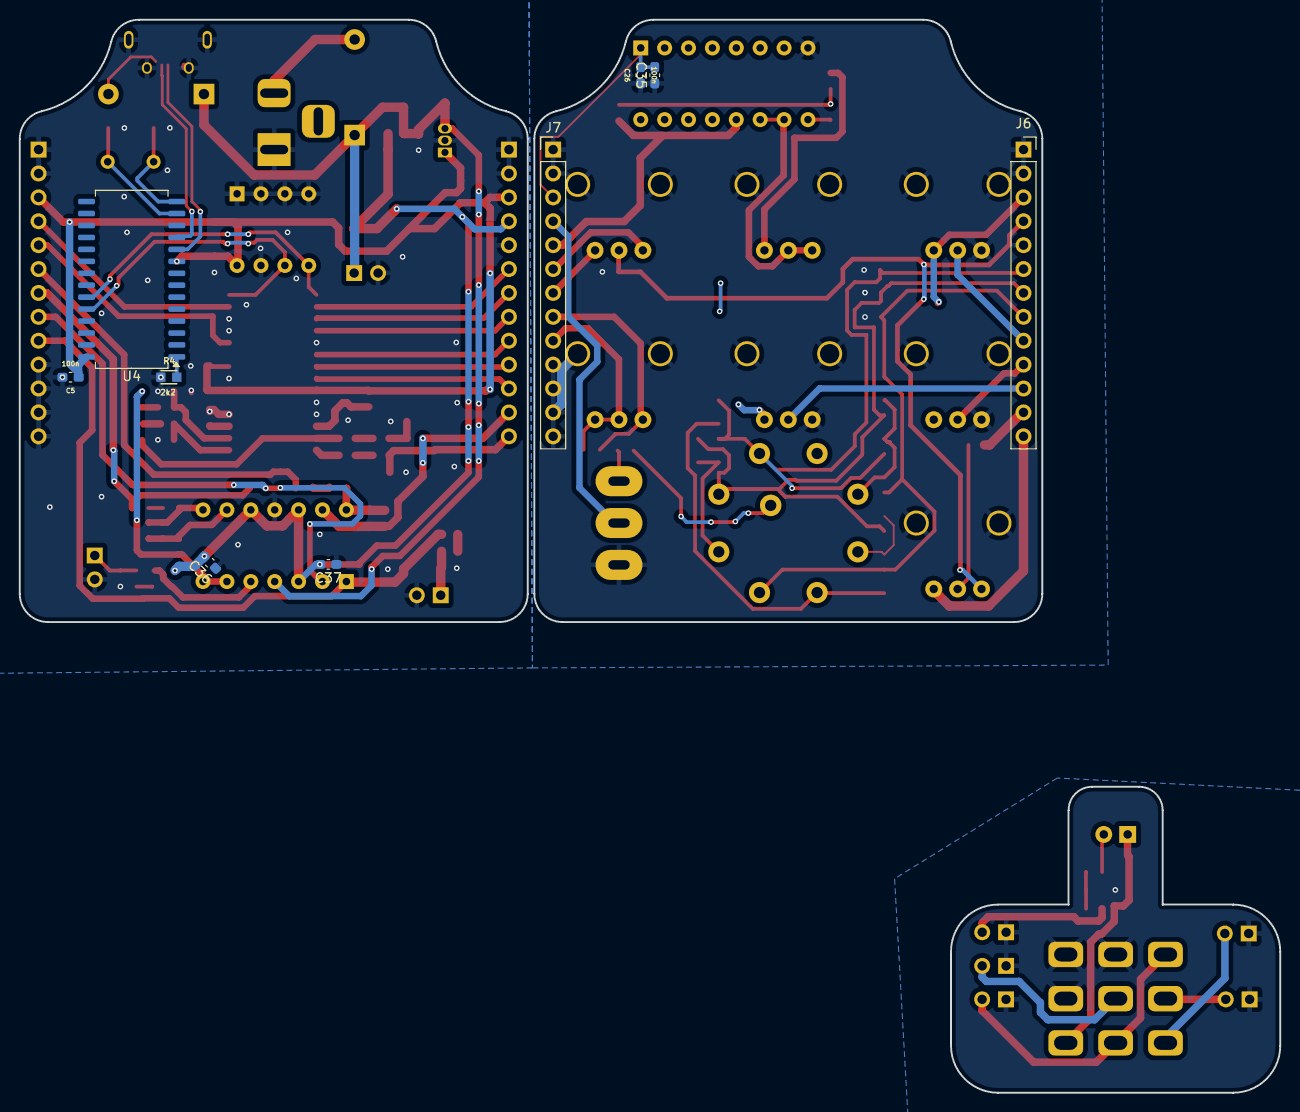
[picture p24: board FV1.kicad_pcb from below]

Board: 2 copper layers, 134.0 x 114.1 mm, 110 parts (9 on the bottom side), 85 nets.
